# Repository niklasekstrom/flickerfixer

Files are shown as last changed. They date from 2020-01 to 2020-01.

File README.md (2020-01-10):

# flickerfixer
An open source flicker fixer for Amiga 500/2000

This is the first stage in the construction of a flicker fixer/scan doubler that mounts internally in an Amiga 500 or Amiga 2000.

In order to rapidly prototype the FPGA logic I designed a small adapter board that connects pins on Denise to a [DE10-Lite](http://de10-lite.terasic.com/) FPGA development board via a 5V-tolerant buffer. The KiCad files for the board are available in [Hardware](Hardware).

After ordering, receiving and soldering the PCB I then wrote Verilog code that samples CSYNC (composite sync) and the 12-bit RGB signals, and outputs the sampled pixels to VGA. The logic handles both non-interlaced and interlaced output from the Amiga. The Quartus project is available in [HDL](HDL).

The next stage is to design a stand-alone board that contains an [FPGA](https://www.mouser.se/ProductDetail/Intel-Altera/10M02SCE144C8G?qs=G%2FX6g08h60tD7HZOc4xZbg%3D%3D) chip and an [SDRAM](https://www.mouser.se/ProductDetail/ISSI/IS42S16400J-6TL?qs=sGAEpiMZZMti5BT4iPSEnRbV70NKySN8V%252BBluA5se8I%3D) chip.

Some pictures:

| | |
| --- |---|
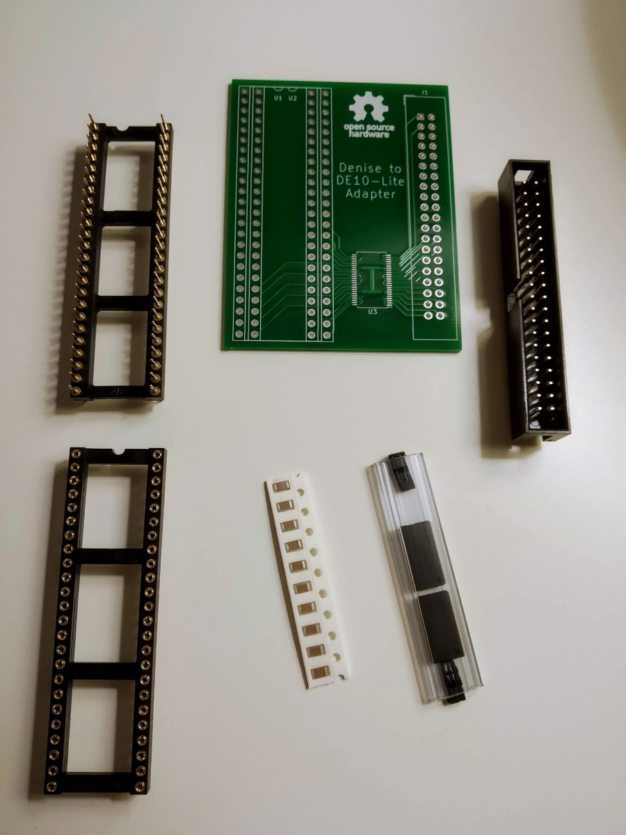
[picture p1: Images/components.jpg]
Components
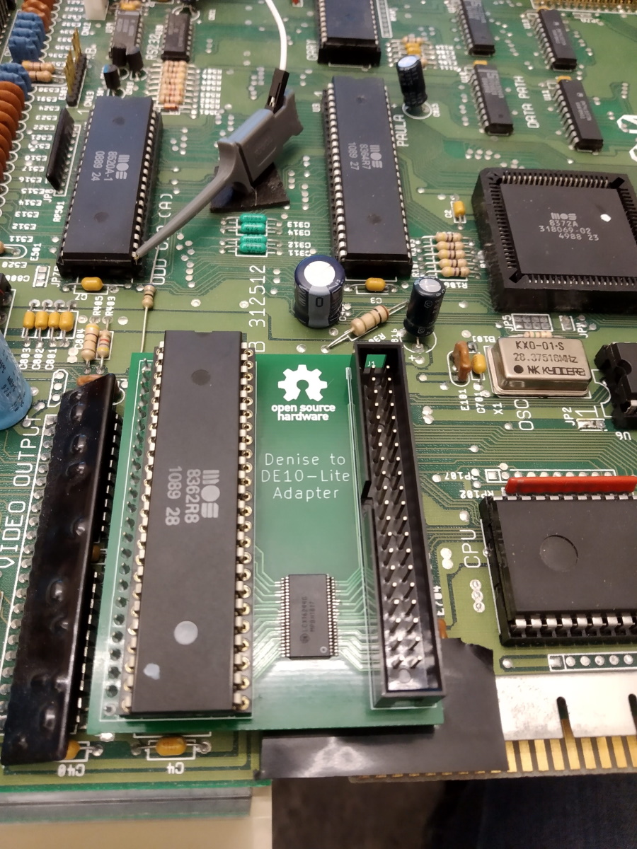
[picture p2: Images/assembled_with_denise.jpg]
Assembled with Denise
|  |  |
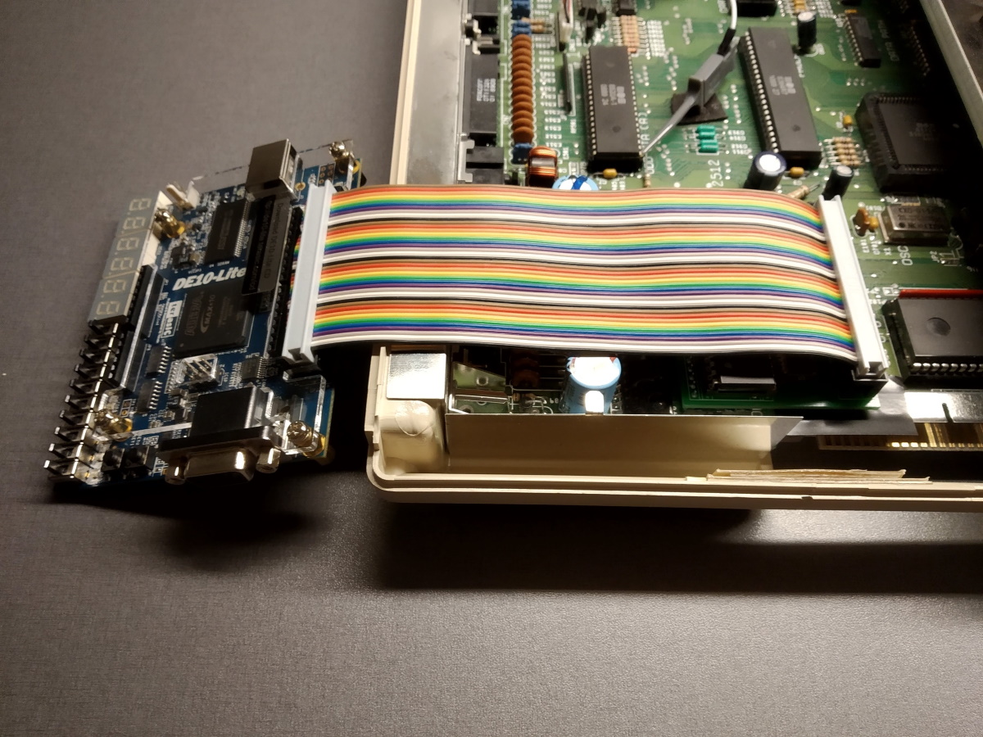
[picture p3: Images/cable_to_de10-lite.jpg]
Cable to DE10-Lite
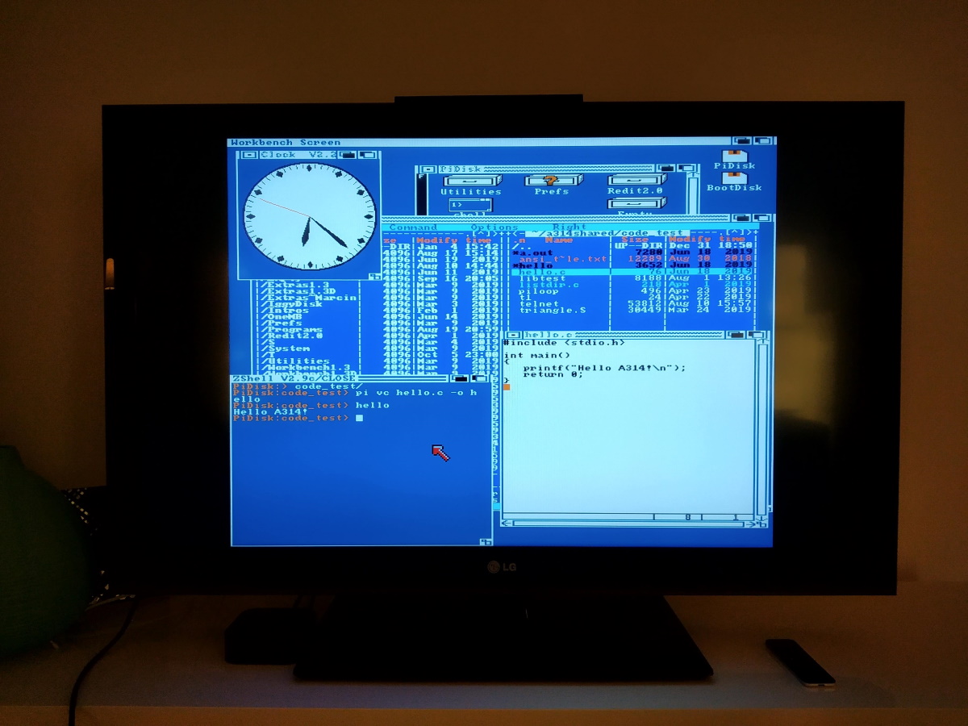
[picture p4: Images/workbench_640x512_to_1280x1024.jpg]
Workbench in 640x512 (interlaced) that is output to VGA at 1280x1024
| |  |

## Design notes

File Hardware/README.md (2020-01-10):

# Components

* A single [74LCX16244](https://www.mouser.se/ProductDetail/ON-Semiconductor-Fairchild/74LCX16244MTD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) buffer chip is used to translate 5V to 3.3V.
* Four 100 nF decoupling capacitors, 1206 size, are mounted on the back of the PCB.
* A 48 pin DIP socket.
* A 48 pin DIP socket whose pins going both up and down, and the legs going down are thinner.
* A 2x20 pin ribbon cable connector.

Components

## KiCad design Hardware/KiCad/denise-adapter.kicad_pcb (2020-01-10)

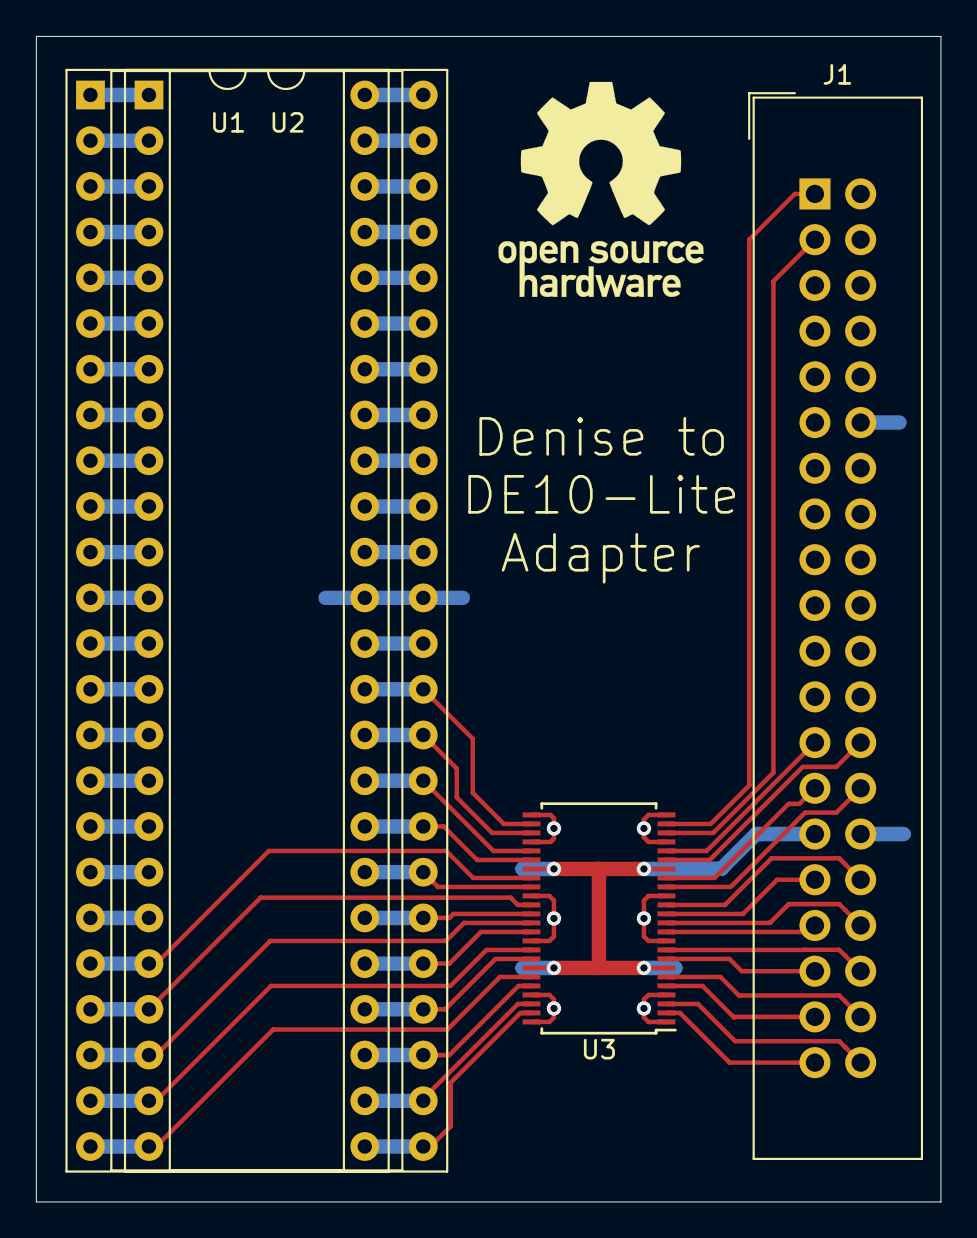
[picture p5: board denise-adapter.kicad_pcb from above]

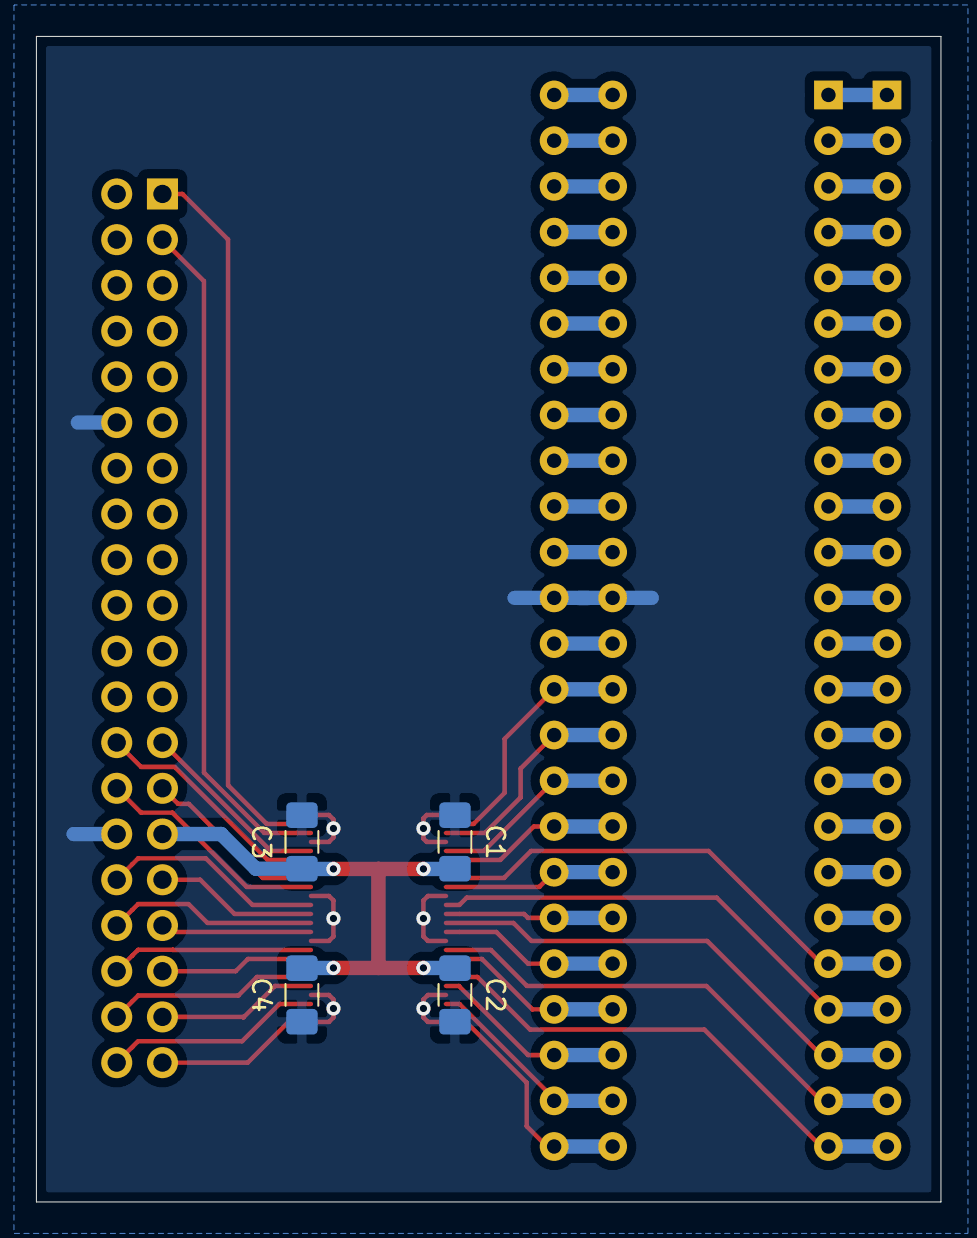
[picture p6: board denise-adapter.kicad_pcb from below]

Board: 2 copper layers, 50.2 x 64.8 mm, 8 parts (4 on the bottom side), 65 nets.

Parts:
C1, C2, C3, C4: 100n; C_1206_3216Metric_Pad1.42x1.75mm_HandSolder
J1: Conn_02x20_Odd_Even; IDC-Header_2x20_P2.54mm_Vertical
U1, U2: 8373_DeniseECS-AmigaCustomChips; DIP-48_W15.24mm_Socket
U3: SN74LVC16244ADGGR; TSSOP-48_6.1x12.5mm_P0.5mm

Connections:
3V7M: J1.1, U3.23
3VB0: J1.38, U3.6
3VB1: J1.39, U3.2
3VB2: J1.40, U3.3
3VB3: J1.37, U3.5
3VCDAC: J1.3, U3.22
3VCSYNC: J1.26, U3.19
3VG0: J1.35, U3.8
3VG1: J1.33, U3.11
3VG2: J1.31, U3.13
3VG3: J1.28, U3.16
3VPIXELSW: J1.25, U3.20
3VR0: J1.27, U3.17
3VR1: J1.32, U3.14
3VR2: J1.34, U3.12
3VR3: J1.36, U3.9
7M: U1.35, U2.35, U3.26
+3V3: C1.1, C2.1, C3.1, C4.1, J1.29, U3.7, U3.18, U3.31, U3.42
+5V: U1.19, U2.19
B0: U1.24, U2.24, U3.43
B1: U1.25, U2.25, U3.47
B2: U1.26, U2.26, U3.46
B3: U1.27, U2.27, U3.44
BURST: U1.18, U2.18
CCK: U1.36, U2.36
CDAC: U1.34, U2.34, U3.27
CSYNC: U1.32, U2.32, U3.30
DRD0: U1.7, U2.7
DRD1: U1.6, U2.6
DRD2: U1.5, U2.5
DRD3: U1.4, U2.4
DRD4: U1.3, U2.3
DRD5: U1.2, U2.2
DRD6: U1.1, U2.1
DRD7: U1.48, U2.48
DRD8: U1.47, U2.47
DRD9: U1.46, U2.46
DRD10: U1.45, U2.45
DRD11: U1.44, U2.44
DRD12: U1.43, U2.43
DRD13: U1.42, U2.42
DRD14: U1.41, U2.41
DRD15: U1.40, U2.40
G0: U1.28, U2.28, U3.41
G1: U1.29, U2.29, U3.38
G2: U1.30, U2.30, U3.36
G3: U1.31, U2.31, U3.33
GND: C1.2, C2.2, C3.2, C4.2, J1.12, J1.30, U1.37, U2.37, U3.1, U3.4, U3.10, U3.15, U3.21, U3.24, U3.25, U3.28, U3.34, U3.39, U3.45, U3.48
M0H: U1.9, U2.9
M0V: U1.38, U2.38
M1H: U1.8, U2.8
M1V: U1.39, U2.39
PIXELSW: U1.33, U2.33, U3.29
R0: U1.20, U2.20, U3.32
R1: U1.21, U2.21, U3.35
R2: U1.22, U2.22, U3.37
R3: U1.23, U2.23, U3.40
RGA1: U1.17, U2.17
RGA2: U1.16, U2.16
RGA3: U1.15, U2.15
RGA4: U1.14, U2.14
RGA5: U1.13, U2.13
RGA6: U1.12, U2.12
RGA7: U1.11, U2.11
RGA8: U1.10, U2.10

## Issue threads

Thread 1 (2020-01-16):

Try finding top-left corner of display window from PIXELSW pin

niklasekstrom, 2020-01-16:
Denise has an output pin PIXELSW that is supposed to indicate if a pixel has the background color or not. It might be possible to use this pin in some clever way to find the top-left corner of the display window (DIWSTRT), which could be used to remove overscan and only output the pixels in the display window. Probably one has to make additional assumptions about the size of the display window for this to work, which may only work in certain circumstances. Experiment!

niklasekstrom, 2020-01-16:
I did a small experiment this evening and the PIXELSW pin does what the documentation says, i.e. it is active if a pixel has the background color.

aiobofh, 2020-01-22:
This is so cool! :)

polluks, 2020-05-12:
BTW what about HDMI and simply skip the analogue part..?

niklasekstrom, 2020-05-12:
@polluks HDMI sounds great, I would like it very much myself. The only reason I'm using VGA is because it is simple and because there's a VGA connector on the [DE10-Lite](https://www.terasic.com.tw/cgi-bin/page/archive.pl?Language=English&No=1021) FPGA dev board.

You don't happen to have a suggestion for a good and easy to use HDMI serializer chip?

polluks, 2020-05-12:
I see, however I'm just a software guy.

WillGreen, 2020-05-12:
HDMI serializer chips are only sold to HDMI Adopters (joining fee $5,000). However, it's relatively straightforward to serialize video data on an FPGA and then output it directly to an HDMI connector (or more robustly via a buffer chip such as the TI TMDS141 - which doesn't require joining the HDMI forum).

I have previously worked on an open-source HDMI design in Verilog for Xilinx FPGAs: https://github.com/projf/display_controller

It should be relatively painless to adapt to Altera.

polluks, 2020-05-12:
Aha, at least better than a simple upscaler.

niklasekstrom, 2020-05-14:
Hi @WillGreen. Thanks for the information! The TFP410 sounds quite interesting.

Regarding serializing HDMI signals on the FPGA, isn't it the case that the frequencies become very high? For example, I want to output [1280x1024@60Hz](http://tinyvga.com/vga-timing/1280x1024@60Hz) which has a pixel clock of 108 MHz, wouldn't that mean that the HDMI frequency is 10 times that, i.e. over 1 GHz, which a 10M02 FPGA certainly can't handle ?

What do you think of buying a chip such as [Analog Devices ADV7513](https://www.analog.com/media/en/technical-documentation/data-sheets/ADV7513.pdf) from AliExpress? I haven't tried buying anything from there yet, and it seems a bit shady with what you wrote about having to be an HDMI adopter, but since it's only for personal use I wouldn't expect there to be any bad consequences, if the chips are actually legitimate. At least the prices seems quite [reasonable](https://www.aliexpress.com/item/32787787233.html).
